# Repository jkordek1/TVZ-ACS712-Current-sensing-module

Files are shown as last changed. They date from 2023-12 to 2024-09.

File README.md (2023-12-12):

# TVZ ACS712 Current sensing module


[]()



 PCB module for ACS712, fully Integrated, Hall Effect-Based Linear Current Sensor with 2.1 kVRMS Voltage Isolation and a Low-Resistance Current Conductor.
 
 ## Features
 - 4mm banana plugs for sensors IP+ and IP- pins
 - 3 different capacitor values for filtering (switchable via jumper pins)
 - powering sensor via miniUSB or male pins
 - power LED
 - Probe clips for easy oscilloscope connections

## Images
<p align="center">
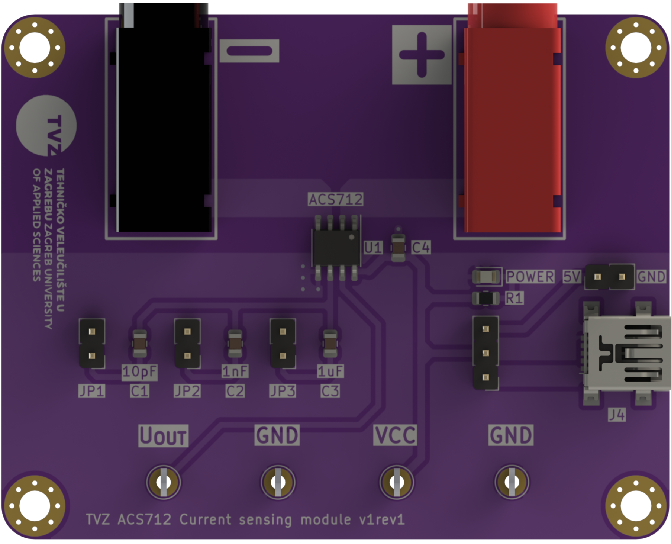
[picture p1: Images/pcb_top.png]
  
</p>

## Project folder structure
    .
    ├── ...
    ├── Images                  # Images of the project
    ├── KiCADFiles              # Main folder
    │   ├── 3D models           # 3d models of components
    │   ├── Datasheet           # Datasheet collection
    │   ├── production          # gerber output folder
    │   ├── myDAQExpansionBoard # Main folder for KiCAD files
    │   └── Schematic.pdf       # Project schematic
    └── ...

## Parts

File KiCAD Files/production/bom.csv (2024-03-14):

Designator | Footprint | Quantity | Value | LCSC Part #
C1 | 0805 | 1 | 10p / 50V
C2 | 0805 | 1 | 1n / 50V
C3 | 0805 | 1 | 1u / 50V
C4 | 0805 | 1 | 100n
C5, C6 | 0805 | 2 | 10uF
D1 | 0805 | 1 | RED
H1, H2, H3, H4 | MountingHole_3.2mm_M3_Pad_Via | 4 | MountingHole_Pad
J1 | DELTRON 4mm banana socket - red | 1 | Banana plug
J2 | DELTRON 4mm banana socket - black | 1 | Banana plug
J5 | BarrelJack_Wuerth_6941xx301002 | 1 | Barrel_Jack_MountingPin
JP1, JP2, JP3 | PinHeader_1x02_P2.54mm_Vertical | 3 | Jumper_2_Bridged
R1 | 0805 | 1 | 1k3
TP1, TP2, TP3, TP4 | KEYS4952 | 4 | TestPoint
U1 | SOIC-8_3.9x4.9mm_P1.27mm | 1 | ACS712
U2 | SOT-223-3_TabPin2 | 1 | AMS1117-5.0

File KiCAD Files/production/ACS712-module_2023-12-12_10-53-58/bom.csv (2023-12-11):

Designator | Footprint | Quantity | Value | LCSC Part #
C1 | 0805 | 1 | 10p / 50V
C2 | 0805 | 1 | 1n / 50V
C3 | 0805 | 1 | 1u / 50V
C4 | 0805 | 1 | 100n
D1 | 0805 | 1 | RED
H1, H2, H3, H4 | MountingHole_3.2mm_M3_Pad_Via | 4 | MountingHole_Pad
J1 | DELTRON 4mm banana socket - red | 1 | Banana plug
J2 | DELTRON 4mm banana socket - black | 1 | Banana plug
J3 | PinHeader_1x02_P2.54mm_Vertical | 1 | power
J4 | USB_Mini-B_Lumberg_2486_01_Horizontal | 1 | USB_B_Mini
JP1, JP2, JP3 | PinHeader_1x02_P2.54mm_Vertical | 3 | Jumper_2_Bridged
JP4 | PinHeader_1x03_P2.54mm_Vertical | 1 | Jumper_3_Open
R1 | 0805 | 1 | 680R
TP1, TP2, TP3, TP4 | KEYS4952 | 4 | TestPoint
U1 | SOIC-8_3.9x4.9mm_P1.27mm | 1 | ACS712

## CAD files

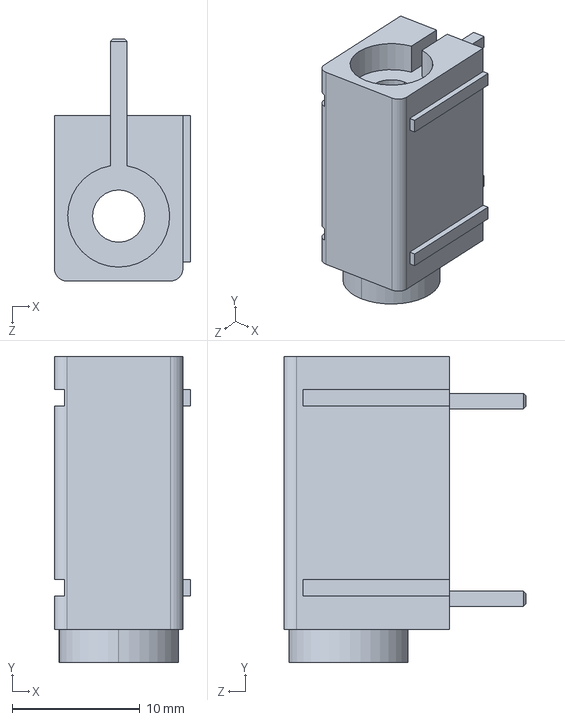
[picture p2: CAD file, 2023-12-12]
KiCAD Files/3D models/AB2_90DEG_4MM_JACK_PTH-BLK.step.SLDPRT
10.7 x 24.0 x 19.0 mm

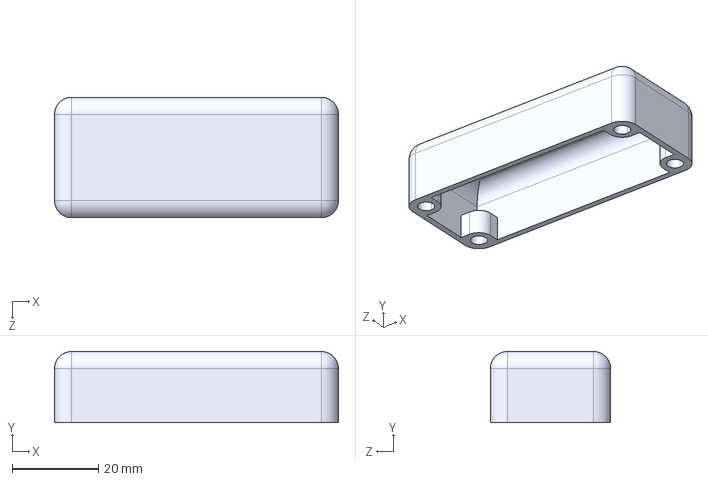
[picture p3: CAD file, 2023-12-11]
KiCAD Files/3D models/Shunt cover guard.STEP
66.0 x 16.5 x 28.0 mm

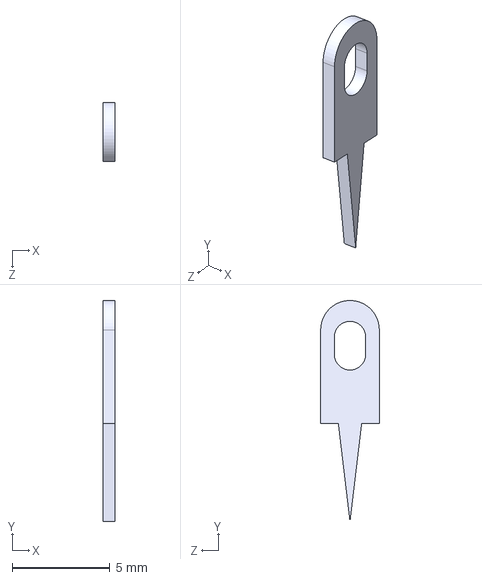
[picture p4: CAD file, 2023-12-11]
KiCAD Files/3D models/KEYS4952.STEP
0.63 x 11.3 x 3.00 mm

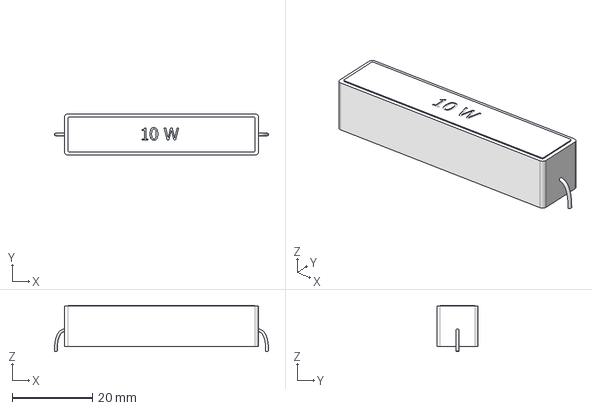
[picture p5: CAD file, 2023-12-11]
KiCAD Files/3D models/PRW0AWJW33JB00.stp
53.3 x 10.3 x 11.5 mm

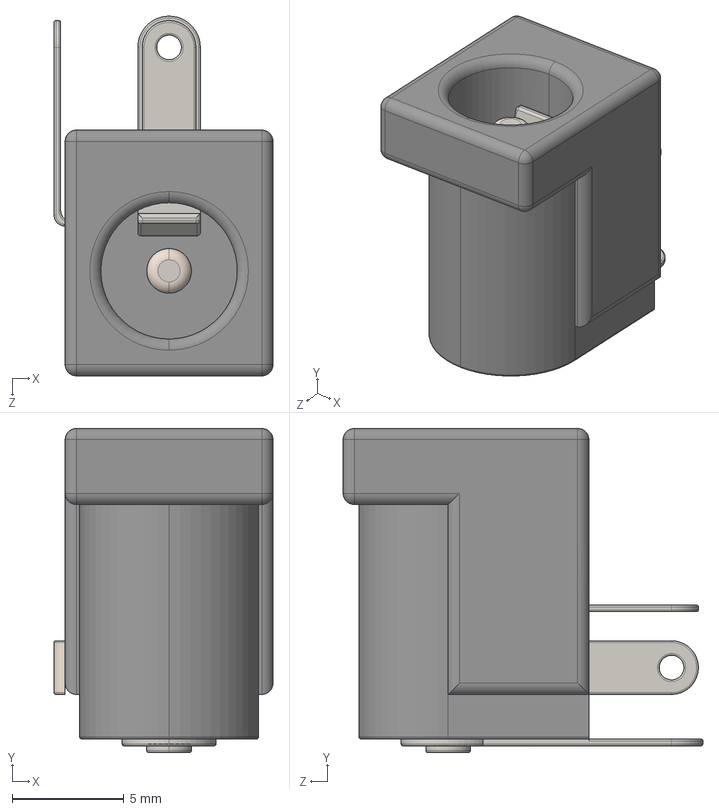
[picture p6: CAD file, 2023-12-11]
KiCAD Files/3D models/K375A -PCM DC Power Jack 2mm Pin.STEP
9.80 x 14.5 x 16.1 mm

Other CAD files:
KiCAD Files/3D models/AB2_90DEG_4MM_JACK_PTH-RED.step.SLDPRT
KiCAD Files/3D models/AB2_90DEG_4MM_JACK_PTH-RED.STEP
KiCAD Files/3D models/Shunt cover guard.SLDPRT

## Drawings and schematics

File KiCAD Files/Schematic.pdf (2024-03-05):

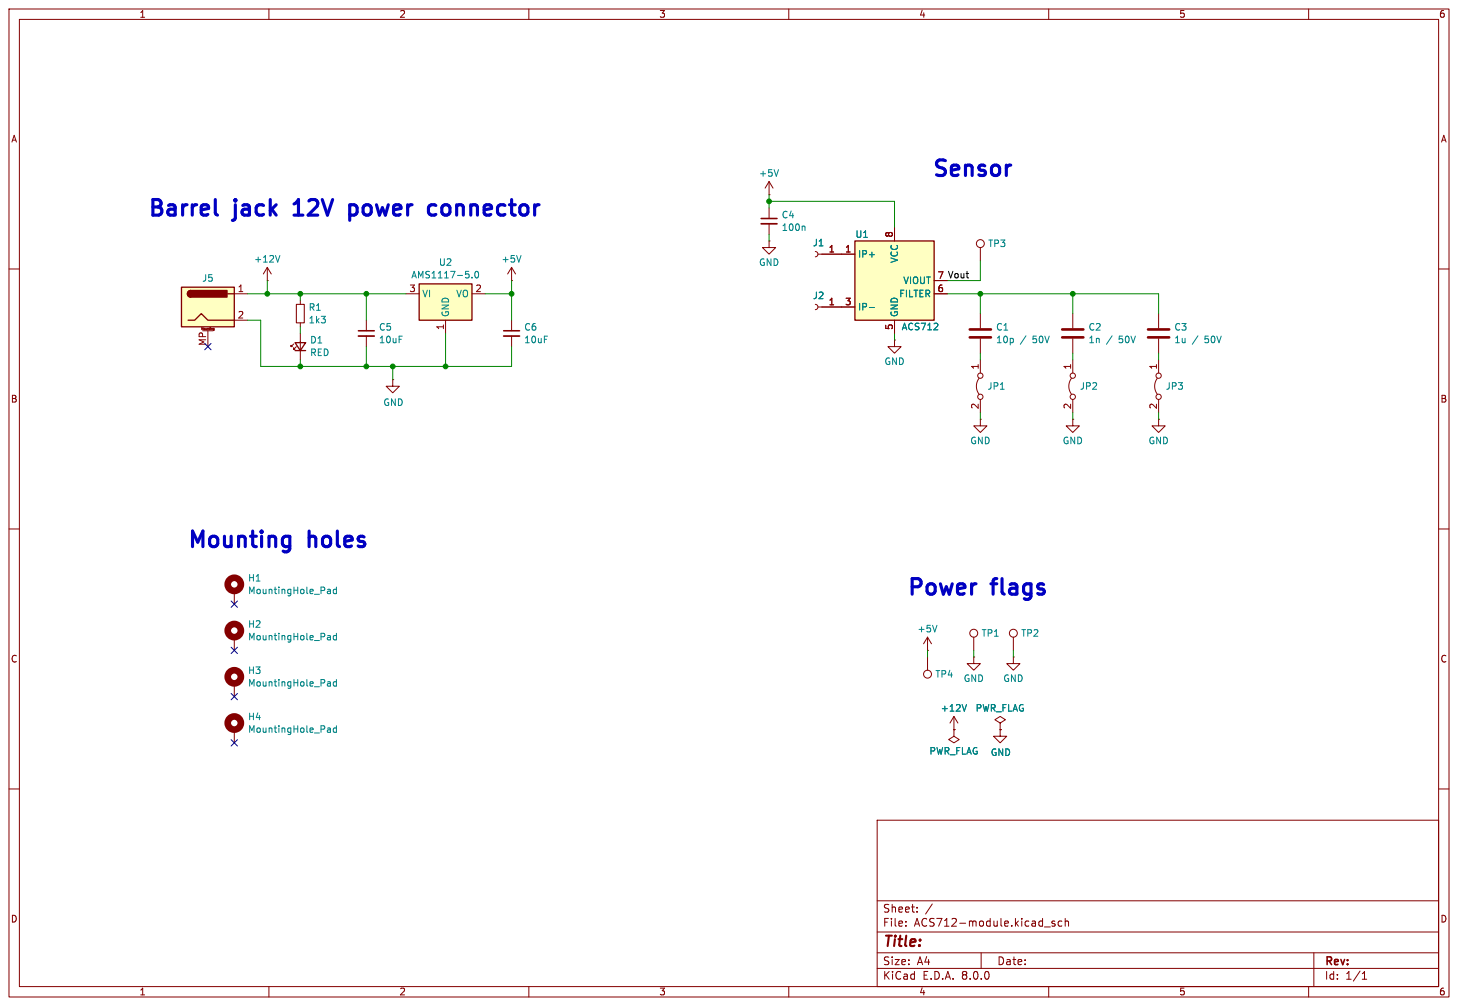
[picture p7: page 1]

Id: 1/1 Title: File: ACS712-module.kicad_sch Sheet: /

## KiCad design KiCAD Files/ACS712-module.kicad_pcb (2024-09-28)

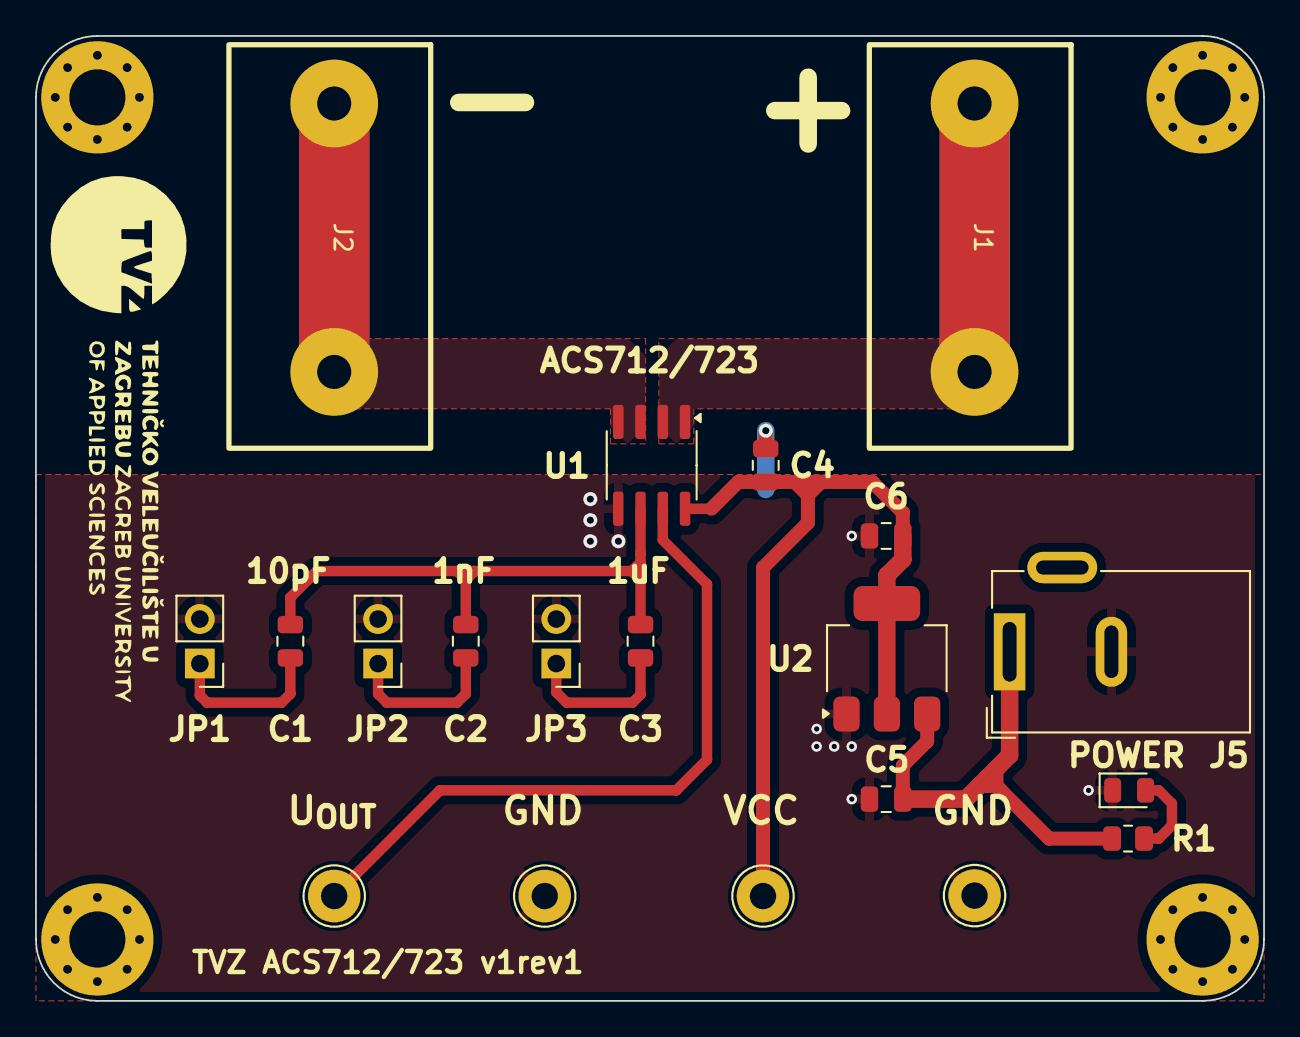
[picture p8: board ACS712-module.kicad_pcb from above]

Board: 2 copper layers, 70.0 x 55.0 mm, 24 parts (0 on the bottom side), 11 nets.

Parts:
C1: 10p / 50V; C_0805_2012Metric
C2: 1n / 50V; C_0805_2012Metric
C3: 1u / 50V; C_0805_2012Metric
C4: 100n; C_0805_2012Metric
C5, C6: 10uF; C_0805_2012Metric
D1: RED; LED_0805_2012Metric
H1, H2, H3, H4: MountingHole_Pad; MountingHole_3.2mm_M3_Pad_Via
J1: Banana plug; DELTRON 4mm banana socket - red
J2: Banana plug; DELTRON 4mm banana socket - black
J5: Barrel_Jack_MountingPin; BarrelJack_Wuerth_6941xx301002
JP1, JP2, JP3: Jumper_2_Bridged; PinHeader_1x02_P2.54mm_Vertical
R1: 1k3; R_0805_2012Metric
TP1, TP2, TP3, TP4: TestPoint; KEYS4952
U1: ACS712; SOIC-8_3.9x4.9mm_P1.27mm
U2: AMS1117-5.0; SOT-223-3_TabPin2

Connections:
+5V: C4.1, C6.1, TP4.1, U1.8 (VCC), U2.2 (VO)
+12V: C5.1, J5.1, R1.1, U2.3 (VI)
/Vout: TP3.1, U1.7 (VIOUT)
GND: C4.2, C5.2, C6.2, D1.1 (K), J5.2, JP1.2 (B), JP2.2 (B), JP3.2 (B), TP1.1, TP2.1, U1.5 (GND), U2.1 (GND)
unnamed: D1.2 (A), R1.2
unnamed: J1.1, U1.1 (IP+), U1.2 (IP+)
unnamed: J2.1, U1.3 (IP-), U1.4 (IP-)
unnamed: C1.2, JP1.1 (A)
unnamed: C2.2, JP2.1 (A)
unnamed: C3.2, JP3.1 (A)
unnamed: C1.1, C2.1, C3.1, U1.6 (FILTER)
